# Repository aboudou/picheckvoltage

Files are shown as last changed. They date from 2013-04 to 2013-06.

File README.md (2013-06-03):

PiCheckVoltage
==============

* [Project's website](http://goddess-gate.com/projects/en/raspi/picheckvoltage)

PiCheckVoltage is a project for the [Raspberry Pi](http://raspberrypi.org) intended to provide a mean to check voltage of a battery pack which is used to power electronic assemblies connected to the Raspberry Pi.

PiCheckVoltage is made of three hardware parts and one software part:

* A voltage regulation unit, which take voltage from the battery pack and provides a +5V regulated power line (to power some IC like port expanders, motor drivers, even Raspberry Pi itself)
* A voltage measurement unit, which check battery pack voltage after it is stepped down to a 0V to 3.3V range by a resistor divider.
* Two status LEDs, which can display if battery pack voltage is good or too low.
* A “kill switch”, which unplug battery when voltage is dangerously low.
* A program to run on the Raspberry Pi, which read mesured voltage, drive status LEDs, and can start three user provided scripts when the battery pack voltage reaches three different levels:
	* 0V level: a.k.a. unplugged battery pack
        * dangerous battery level: when voltage reaches a value which is dangerously low for the batteries
	* low battery level: when voltage reaches a value which is near to be dangerously low for the batteries
	* good battery level: when voltage is over low battery level

You can see the live electronic assembly for PiCheckVoltage on [this photo](http://www.flickr.com/photos/aboudou/8666239532/) which is used to manage [MovingRaspi](http://goddess-gate.com/projects/en/raspi/movingraspi) 

Credits
-------

“mcp3008.py” file provided with PiCheckVoltage comes from [Adafruit-Raspberry-Pi-Python-Code](https://github.com/adafruit/Adafruit-Raspberry-Pi-Python-Code) GitHub repository, and is slightly modified to fit PiCheckVoltage needs.

Requirements
------------

* First of all: a Raspberry Pi
* Electronic parts to build the assembly:
	* For the status LEDs:
		* One green LED (good battery voltage status LED)
		* One yellow LED (low battery voltage status LED)
		* Two 330Ω resistors
	* For the voltage measurement unit:
		* One BCU81 transistor (act as a kill switch when batteries voltage is dangerously low) 
                * One 330Ω resistor to limit the current sent to transistor's base pin
		* One MCP3008 (ADC chip used to read battery voltage)
		* One 10kΩ (R1, connected to positive rail) and one 3.9 kΩ (R2, connected to ground rail) resistor for the voltage divider. These values are chosen to step down voltage from an eight NiMH battery pack — 11.2V max — to about 3.2V max. You may want to adapt these values according the battery pack you choose. Formula for voltage divider is : Vout = Vin * (R2 / (R1 + R2). In this case: 11.2 * (3.9 / (10 + 3.9)) = 3.14
	* For the voltage regulation unit:
		* One BY299 diode (2A diode)
		* One L78S05CV voltage regulator (2A 5V voltage regulator)
		* One 100 µF capacitor (to filter input voltage)
		* One 10 µF capacitor (to filter output voltage)
* Python (with Debian / Raspbian : packages “python” and “python-dev”)
* RPi.GPIO library (0.4.0a or newer) (with Debian / Raspbian : package “python-rpi.gpio”)

To help you with the assembly, you may refer to the following files :

* You may need to download and install [Raspberry Part](https://github.com/adafruit/Fritzing-Library/blob/master/AdaFruit.fzbz) for Fritzing
* picheckvoltage.fzz (into “doc” folder): the assembly mockup to open with Fritzing 
  ([http://fritzing.org/](http://fritzing.org/))

Electronic assembly
-------------------

Mockup on breadboard:
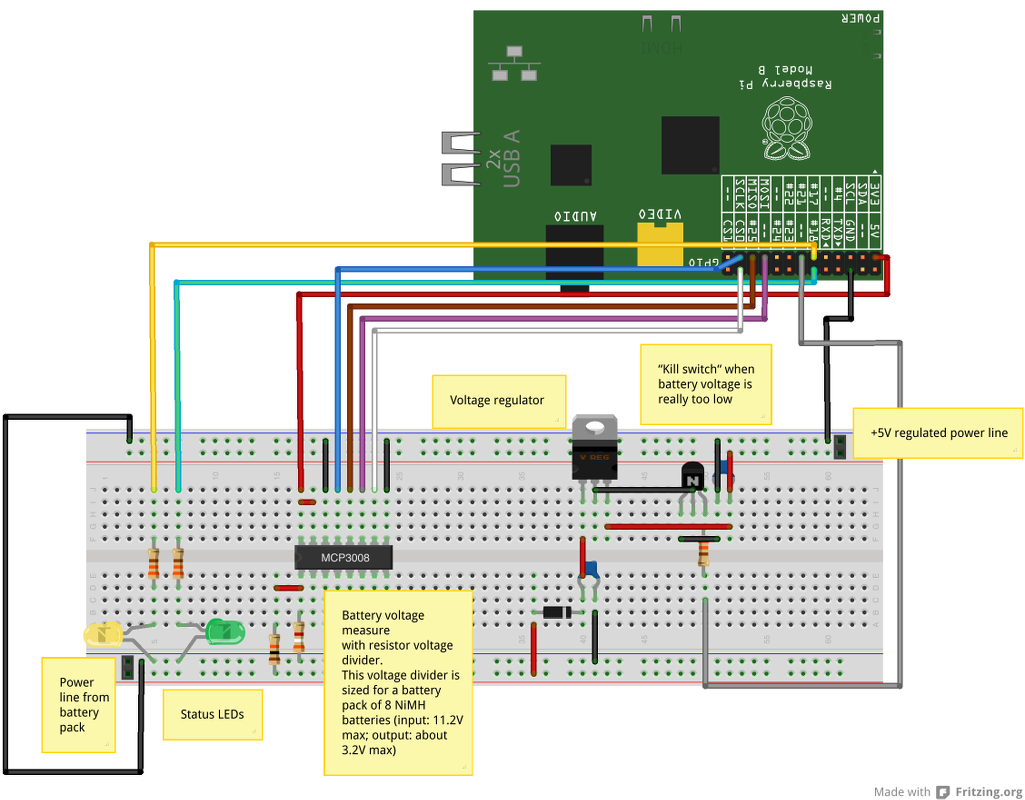
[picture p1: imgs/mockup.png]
Mockup on breadboard


Electronic schematics:
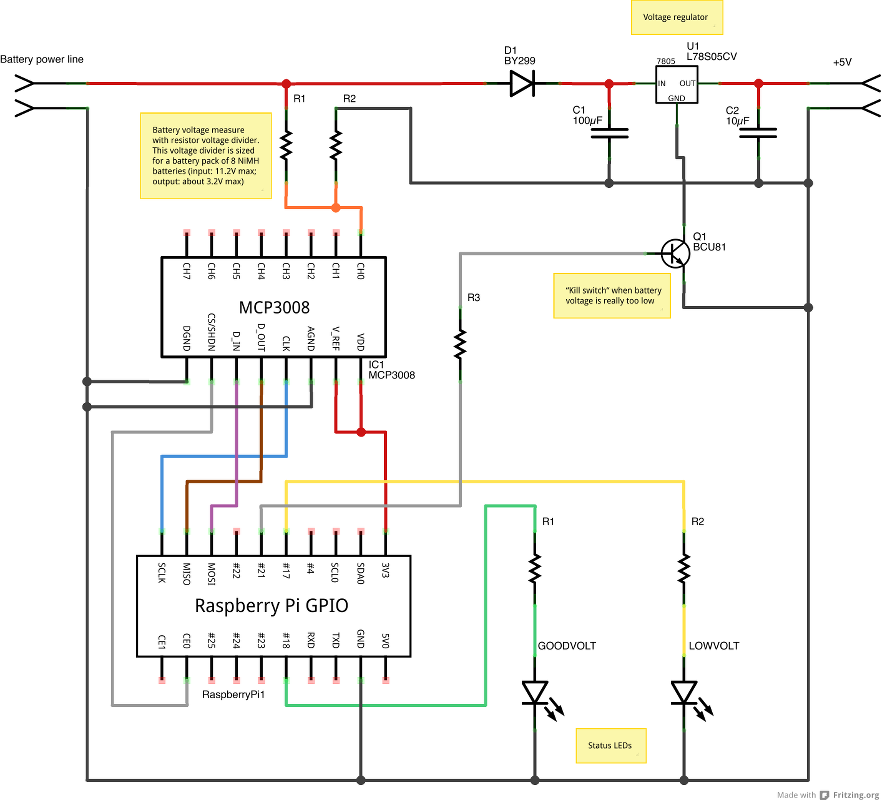
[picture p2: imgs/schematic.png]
Electronic schematics


Live install on [MovingRaspiPlus](https://github.com/aboudou/movingraspi)
Live install on MovingRaspiPlus

How to use PiCheckVoltage
-------------------------

You'll first have to build the electronic assembly, then plug it to the Raspberry Pi

Then copy "config.py.example" file to "config.py" and edit it to fit your needs. Each option is documented.

When you're done, just launch RasPiLEDmeter with `./picheckvoltage.sh start` as root user and that's all :-) When you want / need to stop it, just execute `./picheckvoltage.sh stop` as root user.

Network interface
-----------------

PiCheckVoltage provides a network interface to querie battery status through network. Just connect to it (default port is 50007), and status will be immediately sent, with the following format :

> \<low voltage ADC value\>|\<current voltage adc value\>|\<max voltage adc value\>||\<low voltage value\>|\<current voltage value\>|\<max voltage value\>

* Voltage ADC value is a number between 0 and 1023
* Voltage value is a number using Volt unit

An example return value could be : `731.332897319|853|975.110529758||8.4|9.3296875|11.2`, which means :

* ADC value for minimum battery voltage is around 731.
* ADC value for current voltage is 853.
* ADC value for maximum voltage is around 975.
* Minimum battery voltage is 8.4V.
* Current battery voltage is around 9.33V .
* Maximum battery voltage is 11.2V.

Note : ADC value for maximum voltage may not be equal to 1023 as we have to deal with the imprecision of the resistor voltage divider. With the given example, voltage reference for the ADC is 3.3V (+3.3V power line from Raspberry Pi), and the used resistor divider (10kΩ and 3.9kΩ resistors) steps down 11.2V to 3.14V, not speaking of resistor tolerance.

SIGFOX network push
-------------------

PiCheckVoltage is able to communicate with a SIGFOX serial modem to push battery status to this IoT (Internet of Things) network. Pushed value is current battery voltage, truncated to 10 characters and converted to hexadecimal. Tested modem is TD1202 Evaluation Board.

SIGFOX is a cellular network operator which provides a low cost data transmission service. The service is completely dedicated to low throughput Machine-to-Machine/ Internet of Things applications. See [http://www.sigfox.com](http://www.sigfox.com) for more information.

To use SIGFOX push, you'll have to enable it from “config.py” file, and install PySerial module (on Debian / Raspbian, install package “python-serial”.

You can see [on this page](http://goddess-gate.com/sigfox/) live data pushed by my SIGFOX modem.

Altough originaly intended to be used with a SIGFOX modem, this feature may be used with any serial device.

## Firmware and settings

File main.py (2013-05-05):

#!/usr/bin/python
import RPi.GPIO as GPIO
import time
import array
import os
import signal
import subprocess

import threading
import socket

from config import *
from mcp3008 import *

if SIGFOX_ENABLE == 1:
  try:
    import serial
  except ImportError:
    print ("Unable to import PySerial")
    exit (-1)


STATUSNOBAT = 0
STATUSDNGBAT = 0
STATUSLOWBAT = 0
STATUSGOODBAT = 0
ret = 0

### Functions definition

def runSocketServer():
    s = socket.socket(socket.AF_INET, socket.SOCK_STREAM)
    s.setsockopt(socket.SOL_SOCKET, socket.SO_REUSEADDR, 1)
    s.bind((TCPHOST, TCPPORT))
    s.listen(1)
    while True:
        conn, addr = s.accept()
        conn.sendall(networkData())
        conn.close()

# Called on process interruption. Set all pins to "Input" default mode.
def endProcess(signalnum = None, handler = None):
    GPIO.cleanup()
    socketThread._Thread__stop()
    if STATUSGOODBAT == 1:
        try:
            p = subprocess.Popen(NOBAT_SCRIPT_PATH, stdout=subprocess.PIPE)
        except OSError as detail:
            print ("Could not execute " + NOBAT_SCRIPT_PATH[0] + " ", detail)

    if SIGFOX_ENABLE == 1:
        sigfox.close()

    exit(0)

# Put pins to out mode and low state.
def initPins():
    GPIO.setup(GOODVOLTPIN, GPIO.OUT)
    GPIO.setup(LOWVOLTPIN, GPIO.OUT)
    GPIO.setup(KILLPIN, GPIO.OUT)
    GPIO.output(GOODVOLTPIN, GPIO.LOW)
    GPIO.output(LOWVOLTPIN, GPIO.LOW)
    GPIO.output(KILLPIN, GPIO.LOW)

# Build data send remotely (TCP or SIGFOX network)
def networkData():
    return (str(ADCLOW)+'|'
       +str(ret)+'|'
       +str(ADCHIGH)+'||'
       +str(BATNUMBER*LOWBATVOLT)+'|'
       +str((ret*(BATNUMBER*FULLBATVOLT)/1024)*VCOMP)+'|'
       +str(BATNUMBER*FULLBATVOLT))


def sigfoxData():
    return str((ret*(BATNUMBER*FULLBATVOLT)/1024)*VCOMP)[:10]

### Main part

if DEBUGMSG == 1:
    print("Batteries high voltage:       " + str(VHIGHBAT))
    print("Batteries low voltage:        " + str(VLOWBAT))
    print("Batteries dangerous voltage:  " + str(VDNGBAT))
    print("ADC high voltage value:       " + str(ADCHIGH))
    print("ADC low voltage value:        " + str(ADCLOW))
    print("ADC dangerous voltage value:  " + str(ADCDNG))


# Get current pid
pid = os.getpid()

# Save current pid for later use
try:
    fhandle = open('/var/run/picheckvoltage.pid', 'w')
except IOError:
    print ("Unable to write /var/run/picheckvoltage.pid")
    exit(1)
fhandle.write(str(pid))
fhandle.close()

# Prepare handlers for process exit
signal.signal(signal.SIGTERM, endProcess)
signal.signal(signal.SIGINT, endProcess)

# Use Raspberry Pi board pin numbers
GPIO.setmode(GPIO.BOARD)

# Init output pins
initPins()

socketThread = threading.Thread(None, runSocketServer, None, (), {})
socketThread.daemon = True
socketThread.start()

sigfox = None;
sigfoxPush = 0;
if SIGFOX_ENABLE == 1:
    sigfox = serial.Serial(port=SIGFOX_DEVICE, 
                           baudrate=SIGFOX_DEV_BR, 
                           parity=SIGFOX_DEV_PAR,
                           stopbits=SIGFOX_DEV_SB,
                           bytesize=SIGFOX_DEV_BS)



while True:
    # Read ADC measure on channel ADCCHANNEL
    ret = readadc(ADCCHANNEL, SPICLK, SPIMOSI, SPIMISO, SPICS)
    if DEBUGMSG == 1:
      print("ADC value: " + str(ret) + " (" + str((3.3 / 1024.0) * ret) + " V)")

    if ret < ADCUNP:
        # No battery plugged : we switch all LED off, and run NOBAT_SCRIPT_PATH
        GPIO.output(GOODVOLTPIN, GPIO.LOW)
        GPIO.output(LOWVOLTPIN, GPIO.LOW)
        GPIO.output(KILLPIN, GPIO.LOW)
        if STATUSNOBAT == 0:
            STATUSNOBAT = 1
            STATUSDNGBAT = 0
            STATUSLOWBAT = 0
            STATUSGOODBAT = 0
            try:
                p = subprocess.Popen(NOBAT_SCRIPT_PATH, stdout=subprocess.PIPE)
            except OSError as detail:
                print ("Could not execute " + NOBAT_SCRIPT_PATH[0] + " ", detail)

    elif ret < ADCDNG:
        # Dangerous battery voltage : we switch OK LED off, KO LED on,
        #   and run DNGBAT_SCRIPT_PATH
        GPIO.output(GOODVOLTPIN, GPIO.LOW)
        GPIO.output(LOWVOLTPIN, GPIO.HIGH)
        GPIO.output(KILLPIN, GPIO.LOW)
        if STATUSDNGBAT == 0:
            STATUSNOBAT = 0
            STATUSDNGBAT = 1
            STATUSLOWBAT = 0
            STATUSGOODBAT = 0
            try:
                p = subprocess.Popen(DNGBAT_SCRIPT_PATH, stdout=subprocess.PIPE)
            except OSError as detail:
                print ("Could not execute " + DNGBAT_SCRIPT_PATH[0] + " ", detail)
    
    elif ret < ADCLOW:
        # Test if we were previously in dangerous status and are actually
        #   encountering a voltage bounce situation after kill switch
        #   activation. 
        if STATUSDNGBAT == 1 and ret > ADCDNGBOUNCE:
            # Low battery voltage : we switch OK LED off, KO LED on, 
            #   and run KOBAT_SCRIPT_PATH
            GPIO.output(GOODVOLTPIN, GPIO.LOW)
            GPIO.output(LOWVOLTPIN, GPIO.HIGH)
            GPIO.output(KILLPIN, GPIO.HIGH)
            if STATUSLOWBAT == 0:
                STATUSNOBAT = 0
                STATUSDNGBAT = 0 
                STATUSLOWBAT = 1 
                STATUSGOODBAT = 0
                try:
                    p = subprocess.Popen(KOBAT_SCRIPT_PATH, stdout=subprocess.PIPE)
                except OSError as detail:
                    print ("Could not execute " + KOBAT_SCRIPT_PATH[0] + " ", detail)

    else:
        # Normal battery voltage : we switch OK LED on, KO LED off, 
        #   and OKBAT_SCRIPT_PATH
        GPIO.output(GOODVOLTPIN, GPIO.HIGH)
        GPIO.output(LOWVOLTPIN, GPIO.LOW)
        GPIO.output(KILLPIN, GPIO.HIGH)
        if STATUSGOODBAT == 0:
            STATUSNOBAT = 0
            STATUSDNGBAT = 0
            STATUSLOWBAT = 0
            STATUSGOODBAT = 1
            try:
                p = subprocess.Popen(OKBAT_SCRIPT_PATH, stdout=subprocess.PIPE)
            except OSError as detail:
                print ("Could not execute " + OKBAT_SCRIPT_PATH[0] + " ", detail)

    # Push data to SIGFOX network
    if SIGFOX_ENABLE == 1:
        if sigfoxPush % (SIGFOX_PUSH_RATE / REFRESH_RATE) == 0:
            import datetime
            today = datetime.datetime.today()
            sigfox.write("at$ss=" + sigfoxData().encode("hex") + "\r")
            if DEBUGMSG == 1:
                print today.strftime("%Y-%m-%d %H:%M:%S - Sent to SIGFOX: " 
                                   + sigfoxData().encode("hex")
                                   + " a.k.a " + sigfoxData() 
                                   + "(V) in hexadecimal")
        sigfoxPush = sigfoxPush + 1
        # You don't want the counter to become too big :)
        if sigfoxPush > (SIGFOX_PUSH_RATE / REFRESH_RATE):
            sigfoxPush = 1

    # Pause before starting loop once again
    time.sleep(REFRESH_RATE / 1000)

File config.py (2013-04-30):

"""
" Edit below this line to fit your needs
"""

## Path of the scripts which will run by checkvoltage
# Script to run when no battery is plugged (array with script then parameters)
NOBAT_SCRIPT_PATH = ["/root/raspberrypi/movingraspi/MovingRaspiPlus/Server/movingraspi.sh", "stop"]
# Script to run when battery voltage is dangerously low (array with script then
#   parameters)
DNGBAT_SCRIPT_PATH = ["/root/pcvscripts/batterymail.sh", "&"]
# Script to run when battery voltage is low (array with script then parameters)
KOBAT_SCRIPT_PATH = ["/root/raspberrypi/movingraspi/MovingRaspiPlus/Server/movingraspi.sh", "stop"]
# Script to run when battery voltage is good (array with script then parameters)
OKBAT_SCRIPT_PATH = ["/root/raspberrypi/movingraspi/MovingRaspiPlus/Server/movingraspi.sh", "start"]

# GPIO (BOARD numbering scheme) pin for good voltage LED
GOODVOLTPIN = 11
# GPIO (BOARD numbering scheme) pin for low voltage LED
LOWVOLTPIN = 12
# GPIO (BOARD numbering scheme) pin for kill switch (LOW value to stop powering
#   assembly) 
KILLPIN = 13

## Define voltages
# Number of batteries in series
BATNUMBER = 8.0
#BATNUMBER = 3.0
# Fully charged voltage (for a single battery); 
#   i.e. 1.4V for a NiMH battery, or 4.2V for a LiPo battery
FULLBATVOLT = 1.4
#FULLBATVOLT = 4.2
# Discharged voltage (for a single battery); 
#   i.e. 1.05V for a NiMH battery, or 3.1V for a LiPo battery
#   You should use a conservative value in order to avoid destructive
#   discharging
LOWBATVOLT = 1.05
#LOWBATVOLT = 3.1
# Dangerous voltage (for a single battery);
#   i.e. 1.0V for a NiMH battery, or 3.05V for a LiPo battery
#   You should really not go below this voltage.
DNGBATVOLT = 1.0
#DNGBATVOLT = 3.05

# Value (in ohms) of the lower resistor from the voltage divider, connected to
#   the ground line (1 if no voltage divider). Default value (3900) is for a 
#   battery pack of 8 NiMH batteries, providing 11.2V max, stepped down to about
#   3.2V max.
LOWRESVAL = 3900
# Value (in ohms) of the higher resistor from the voltage divider, connected to 
#   the positive line (0 if no voltage divider). Default value (10000) is for a
#   battery pack of 8 NiMH batteries, providing 11.2V max, stepped down to about
#   3.2V max.
HIGHRESVAL = 10000
# Voltage value measured by the MCP3008 when batteries are fully charged
# It should be near 3.3V due to Raspberry Pi GPIO compatibility)
VHIGHBAT = (BATNUMBER*FULLBATVOLT)*(LOWRESVAL)/(LOWRESVAL+HIGHRESVAL)
# Voltage value measured by the MCP3008 when batteries are discharged
VLOWBAT = (BATNUMBER*LOWBATVOLT)*(LOWRESVAL)/(LOWRESVAL+HIGHRESVAL)
# Voltage value measured by the MCP3008 when batteries voltage is dangerously
#   low
VDNGBAT = (BATNUMBER*DNGBATVOLT)*(LOWRESVAL)/(LOWRESVAL+HIGHRESVAL)

# ADC voltage reference (3.3V for Raspberry Pi)
ADCVREF = 3.3

# Compensation due to the difference between ADC voltage reference and 
#   max value for voltage through resistor divider
#   i.e. : with the given resistances values, VREF is 3.3 V, and max voltage
#   through resistor divider is about 3.14V, leading to about 4.8% deviation.
# This compensation is used to correct computed battery voltage return by
#   network queries
VCOMP = 1+(ADCVREF-VHIGHBAT)/ADCVREF

## Define expected ADC values
# MCP23008 channel to use (from 0 to 7)
ADCCHANNEL = 0
# MCP23008 should return this value when batteries are fully charged
#  * 3.3 is the reference voltage (got from Raspberry Pi's +3.3V power line)
#  * 1024.0 is the number of possible values (MCP23008 is a 10 bit ADC)
ADCHIGH = VHIGHBAT / (ADCVREF / 1024.0)
# MCP23008 should return this value when batteries are discharged
#  * 3.3 is the reference voltage (got from Raspberry Pi's +3.3V power line)
#  * 1024.0 is the number of possible values (MCP23008 is a 10 bit ADC)
ADCLOW = VLOWBAT / (ADCVREF / 1024.0)
# MCP23008 should return this value when batteries atteigns dangerous voltage
#  * 3.3 is the reference voltage (got from Raspberry Pi's +3.3V power line)
#  * 1024.0 is the number of possible values (MCP23008 is a 10 bit ADC)
ADCDNG = VDNGBAT / (ADCVREF / 1024.0)
# MCP should return a value lower than this one when no battery is plugged.
# You should not use 0 because value is floatting around 0 / 150 when nothing
#  is plugged to a analog channel. 
ADCUNP = 300 # No battery plugged

# Refresh rate (ms)
REFRESH_RATE = 1000

# Hostname or IP address to listen for network queries. '' for all interfaces
TCPHOST = ''
# TCP port
TCPPORT = 50007
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

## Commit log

2013-04-21 Initial import
    [picheckvoltage.fzz]
2013-04-21 Add schematics and mockup for README.md
2013-04-21 Added schematics and mockup
2013-04-23 Added network interface to query battery status
2013-04-25 Added a “kill switch” when batteries voltage is dangerously low
    [picheckvoltage.fzz]
2013-04-26 Fix computed battery voltage returned by network queries
    [config.py, main.py]
2013-05-02 Fix issue which can lead to infinite script execution
    [main.py]
2013-05-05 Fix issue with voltage bounce when kill switch is enabled
    [main.py]
